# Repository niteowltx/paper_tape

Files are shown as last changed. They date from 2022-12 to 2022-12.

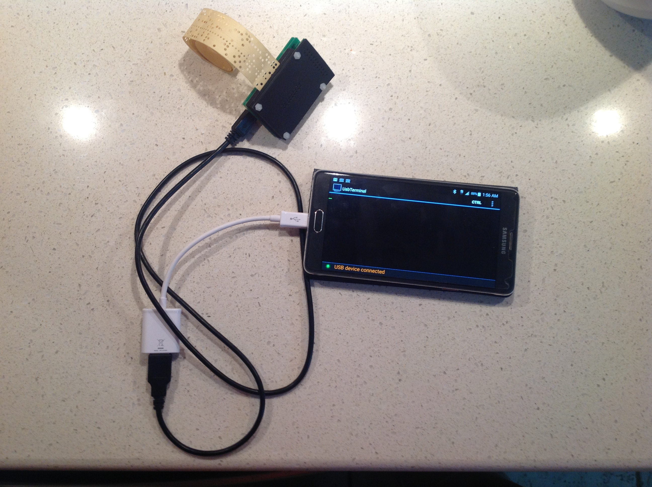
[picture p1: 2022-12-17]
paper_tape.jpg

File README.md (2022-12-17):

A Paper Tape Reader for ancient ASR33 class paper tapes.

	Paper is 1" wide with 9 holes on 0.1" centers.  Rows are also 0.1" apart.
	Data holes are 0.072" diameter, sprocket hole is 0.046" diameter
	Sprocket is small so it works as a strobe for the data

	Paper Tape layout:
		D0 D1 D2 St D3 D4 D5 D6 D7

Hardware:
	3D printed paper tape guide (top and bottom)

	top board: IR LED array (OSRAM SFH-4949), pullup resistor network (2K ohms)

	bottom board: Photo diode array (OSRAM BPX89), pulldown resistor network (1K ohms)

	process board: Adafruit Metro Mini, USB power and serial in/out

	Top and Bottom boards are identical, just flipped and populated differently.  Top
		board (IR LED) only connects +5 and Gnd.

	Signal cleanup between the Photodiode array and the Arduino are not necessary
		since the ATmega328 has Schmitt triggers built in.

	Photodiode Array to Arduino wiring:

		D0 -> PB0 -> Digital Pin 8
		D1 -> PB1 -> Digital Pin 9
		D2 -> PB2 -> Digital Pin 10
		D3 -> PB3 -> Digital Pin 11
		D4 -> PB4 -> Digital Pin 12
		D5 -> PD5 -> Digital Pin 5
		D6 -> PD6 -> Digital Pin 6
		D7 -> PD7 -> Digital Pin 7
		St -> PD2 -> Digital Pin 2 (INT0)

		To read all 8 bits in 2 reads from I/O Ports:
			byte = (PINB & 0x1F) | (PIND & 0xE0);

Software:
	Strobe generates interrupt on Arduino which reads byte and puts it in a FIFO.
		FIFO is 1000 bytes deep to allow for irregularites in serial output and
		the speed at which the loop() function is called.

	Main loop pulls bytes from FIFO and sends them via USB serial to host.

	Bytes are printed in HEX and a 2-character ASCII representaion of the lower 7-bits

	Serial output is set to 115200 which is fast enough for 96 ft/sec when the raw bytes
		from the tape are just sent over the serial port.  Printing bytes with a little formatting
		in HEX and printable ASCII reduces this to 16 ft/sec.

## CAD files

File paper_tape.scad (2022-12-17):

$fn					= 32;
//
// Paper Tape Reader
//
//	Paper guide and holder for IR LED & Photodiode arrays
//
// all dimensions in mm
//

// Paper tape dimensions (EIA Std RS-227 / RS-244)
perf_pitch		= 2.540;				// distance between punches on paper (horizontal and vertical)
perf_count		= 9;					// perforations per row
paper_width		= (perf_count+1)*perf_pitch; // (1 inch)
perf_small_r		= (1.1684/2);		// feed hole radius (0.046 inch diameter)
perf_large_r		= (1.8288/2);		// data hole radius (0.072 inch diameter)
paper_thick		= 0.10;				// paper thickness
strip_len	= 29;							// sample paper strip length, in frames

// Sensor dimensions
sensor_width		= perf_pitch+1;		// slightly wider than perf_pitch to accomodate sensor leads
sensor_height	= 3.632;				// height of ir led and photodiode arrays

// Paper tape guide
plate_w			= 38.1;			// 1.5 in
plate_h			= 53.34;			// 2.1 in
guide_offset		= sensor_height/3;	// raise top and lower bottom paper guide slot by this much

// PCB parameters
pcb_w				= plate_w;						// 1.5 in
pcb_h				= plate_h + (perf_pitch*4);	// 2.5 in
pcb_thick			= 1.5;

// Mounting screw hole diameter and radius
mhole_d			= 3;					// M3 nylon screws and nuts
mhole_r			= mhole_d/2;

module paper(n)
{
	color("Green")
	for(i=[0:n-1])
	translate([0,perf_pitch*i,0])
	difference(){
		cube([paper_width,perf_pitch,paper_thick]);
		for(p=[1:perf_count]){
			if(p==4)
				translate([(perf_pitch)*p,perf_pitch/2,0])
					cylinder(r=perf_small_r,h=paper_thick*3,center=true);
			else
				translate([(perf_pitch)*p,perf_pitch/2,0])
					cylinder(r=perf_large_r,h=paper_thick*3,center=true);
		}
	}
}

module mounting_holes(thick)
{
		translate([ plate_w/2-mhole_d, plate_h/2-mhole_d,0])cylinder(r=mhole_r,h=thick*2,center=true);
		translate([-plate_w/2+mhole_d, plate_h/2-mhole_d,0])cylinder(r=mhole_r,h=thick*2,center=true);
		translate([ plate_w/2-mhole_d,-plate_h/2+mhole_d,0])cylinder(r=mhole_r,h=thick*2,center=true);
		translate([-plate_w/2+mhole_d,-plate_h/2+mhole_d,0])cylinder(r=mhole_r,h=thick*2,center=true);
}

module bracket(thick)
{
	difference() { 
		cube(size=[plate_w,plate_h,thick],center=true);		// base
		mounting_holes(thick);

	}
}

module sensor_slot()
{
	cube(size=[sensor_width,perf_pitch*perf_count,sensor_height+20],center=true);	// sensor slot
}

module paper_guide_bottom()
{
	color("SteelBlue")
	difference() {
		rotate(180,[0,1,0])bracket(sensor_height+guide_offset);
		sensor_slot();
		translate([0,0,sensor_height-guide_offset])cube(size=[plate_h+1,paper_width,sensor_height],center=true);	// paper guide
	}
}

module paper_guide_top()
{
	color("LightSteelBlue")
	difference() {
		union() {
			bracket(sensor_height-guide_offset);
			translate([0,0,-guide_offset])cube(size=[plate_w,paper_width,sensor_height],center=true); // paper guide
		}
		sensor_slot();
	}
}

module holes(n)
{
	for(i=[0:n-1])
	translate([0,perf_pitch*i,0])
		cylinder(r=perf_pitch/4,h=5,center=true);
	

}

module resistor_pack()
{
	rotate(90,[0,0,1])
	translate([plate_h/2+perf_pitch,(-perf_pitch*10)/2,0])
	holes(10);
}

module connector()
{
	rotate(90,[0,0,1])
	translate([plate_h/2+(perf_pitch*2),(-perf_pitch*10)/2,0])
	holes(11);
}

module sensor_board()
{
	color("Yellow")
	difference() {
		translate([0,perf_pitch*2,0])cube(size=[pcb_w,pcb_h,pcb_thick],center=true);	// circuit board
		translate([perf_pitch/2,(-perf_pitch*8)/2,0])holes(9);	// sensor holes
		translate([-perf_pitch/2,(-perf_pitch*8)/2,0])holes(9);	// sensor holes
		mounting_holes(2);		// mounting holes
		resistor_pack();
		connector();
	}
}

module dip(pins,spacing)
{
	translate([-spacing/2,0,0])holes(pins);
	translate([spacing/2,0,0])holes(pins);
}

module main_board()
{
	color("Orange")
	difference() {
		translate([0,perf_pitch*2,0])cube(size=[pcb_w,pcb_h,pcb_thick],center=true);	// circuit board
		mounting_holes(2);		// mounting holes
		connector();
		translate([0,-perf_pitch*7,0])dip(14,perf_pitch*6);	// Adafruit Metro Mini
	}
}

module assembly()
{
	translate([0,0,0])paper_guide_bottom();
	translate([0,0,sensor_height*2])paper_guide_top();
	translate([0,0,-sensor_height*1])sensor_board();	// bottom board: photodiodes
	rotate(180,[0,1,0])translate([0,0,-sensor_height*2.5])sensor_board();	// top board: IR led's
	translate([0,0,-sensor_height*2])main_board();		// main board: arduino
	rotate(90,[0,0,-1])translate([-paper_width/2,-(perf_pitch*strip_len/2),1])paper(strip_len);
}

module all()
{
	assembly();
}

module pieces()
{
	rotate(180,[0,1,0])translate([plate_w*.66,0,0])paper_guide_top();
	translate([plate_w*.66,0,0])paper_guide_bottom();
	translate([plate_w*0.66,pcb_h,0])sensor_board();
	translate([-plate_w*0.66,pcb_h,0])sensor_board();
	translate([plate_w*2,0,0])main_board();
}

all();
//pieces();

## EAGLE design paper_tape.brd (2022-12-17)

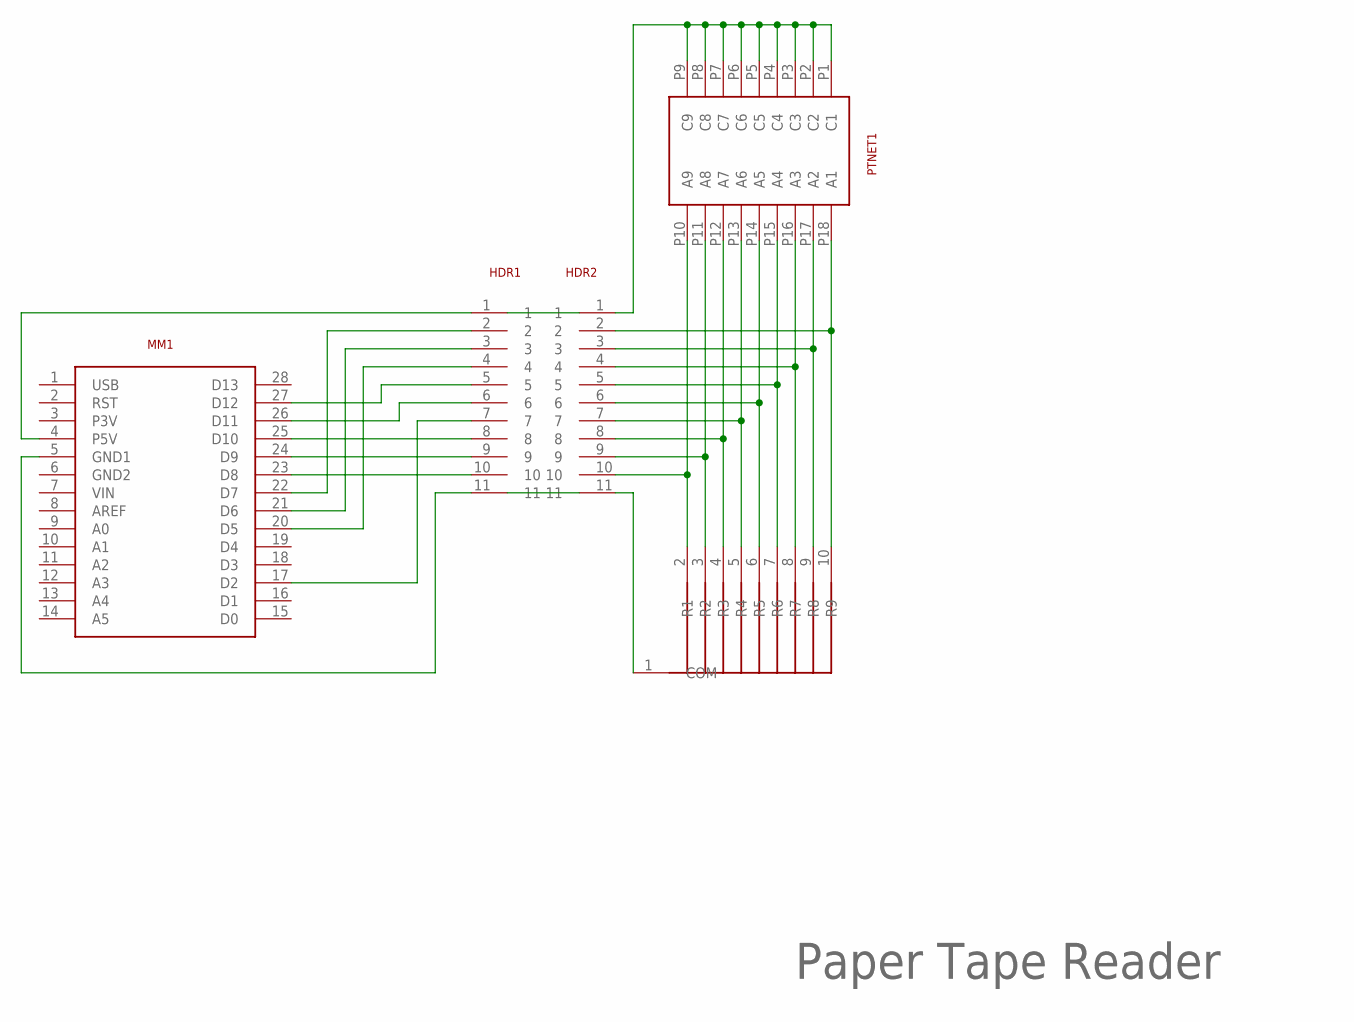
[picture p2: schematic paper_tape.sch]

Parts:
HDR1, HDR2: HEADER; SIP11
MM1: METRO_MINI; DIP28
PTNET1: PBX89; DIP18N
RN1: 1k; SIP10

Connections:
GND: HDR1.11, HDR2.11, MM1.5 (GND1), RN1.1 (COM)
unnamed: HDR1.7, MM1.17 (D2)
unnamed: HDR1.6, MM1.26 (D11)
unnamed: HDR1.5, MM1.27 (D12)
unnamed: HDR1.4, MM1.20 (D5)
unnamed: HDR1.3, MM1.21 (D6)
unnamed: HDR1.2, MM1.22 (D7)
unnamed: HDR1.1, MM1.4 (P5V)
unnamed: HDR1.8, MM1.25 (D10)
unnamed: HDR1.9, MM1.24 (D9)
unnamed: HDR1.10, MM1.23 (D8)
P5V: HDR2.1, PTNET1.P1 (C1), PTNET1.P2 (C2), PTNET1.P3 (C3), PTNET1.P4 (C4), PTNET1.P5 (C5), PTNET1.P6 (C6), PTNET1.P7 (C7), PTNET1.P8 (C8), PTNET1.P9 (C9)
PT_D0: HDR2.10, PTNET1.P10 (A9), RN1.2 (R1)
PT_D1: HDR2.9, PTNET1.P11 (A8), RN1.3 (R2)
PT_D2: HDR2.8, PTNET1.P12 (A7), RN1.4 (R3)
PT_D3: HDR2.6, PTNET1.P14 (A5), RN1.6 (R5)
PT_D4: HDR2.5, PTNET1.P15 (A4), RN1.7 (R6)
PT_D5: HDR2.4, PTNET1.P16 (A3), RN1.8 (R7)
PT_D6: HDR2.3, PTNET1.P17 (A2), RN1.9 (R8)
PT_D7: HDR2.2, PTNET1.P18 (A1), RN1.10 (R9)
PT_STROBE: HDR2.7, PTNET1.P13 (A6), RN1.5 (R4)

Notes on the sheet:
Paper Tape Reader

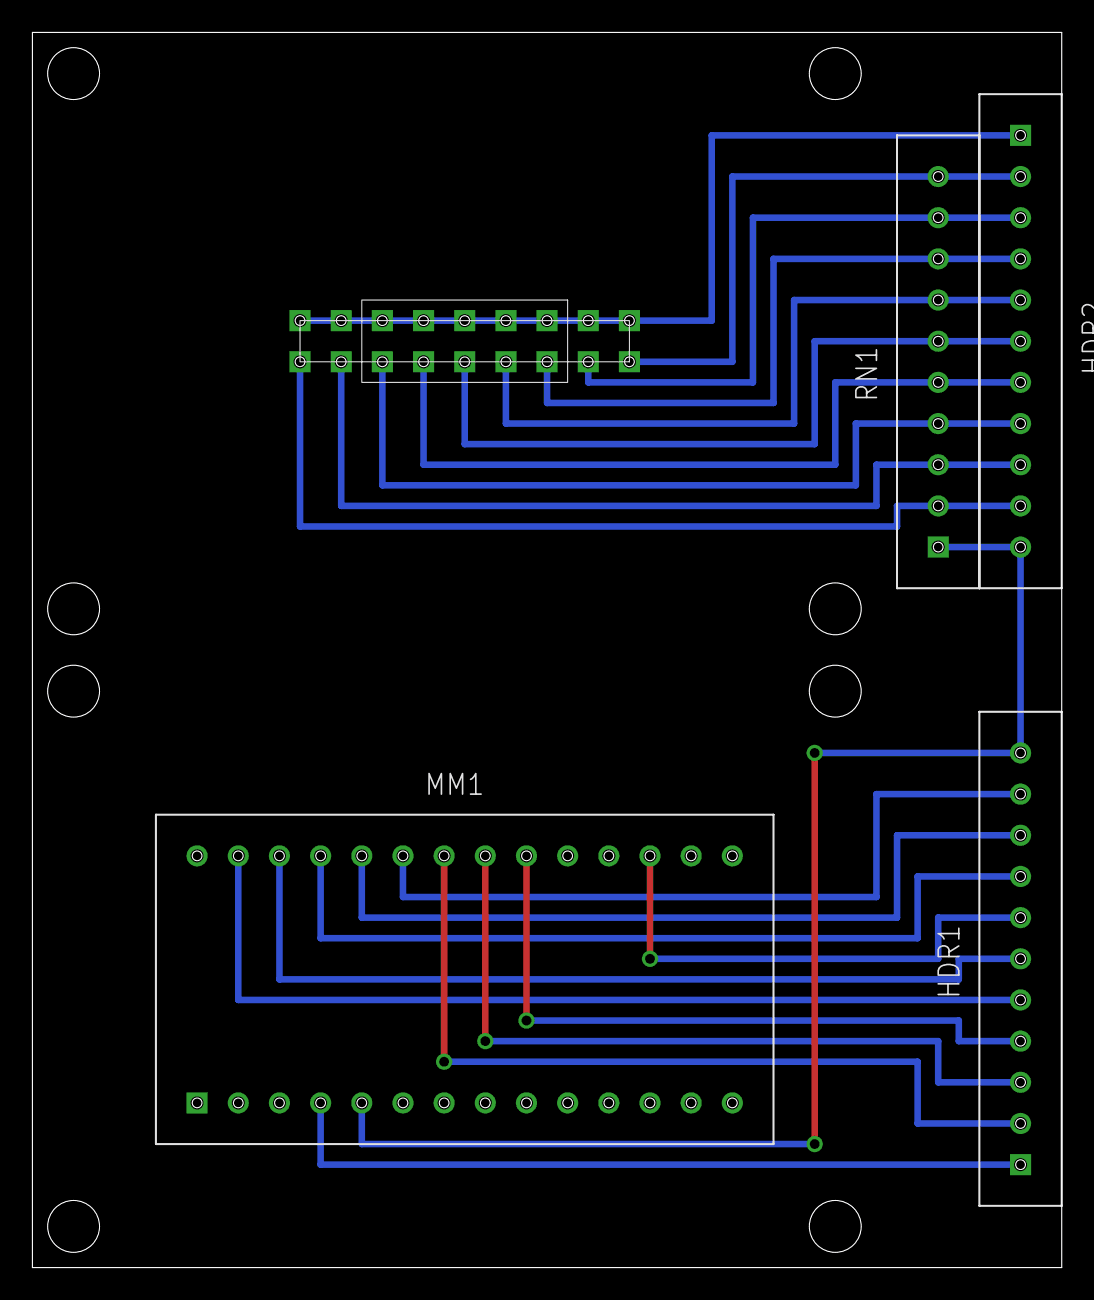
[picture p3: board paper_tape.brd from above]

Board: 2 copper layers, 63.5 x 76.2 mm, 5 parts (0 on the bottom side), 21 nets.

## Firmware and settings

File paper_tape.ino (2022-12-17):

//
// Paper Tape Reader
//
// Read data from ancient paper tapes.  Tape is 1" wide with 8 data
// holes and 1 sprocket hole which is used to strobe the data since it
// is slightly smaller than the data holes.
//
// There are 9 inputs from the photodiode array: D0-D7 and Strobe
// The tape layout is:  D0 D1 D2 Strobe D3 D4 D5 D6 D7
//
// The rising strobe pin is attaced to an interrupt handler which
// picks up the current byte and puts it in a FIFO.  The main
// processing loop simply waits for characters to arrive in the FIFO
// and sends them out the serial port.
//
// Normally pins are read via digitalRead() but to do it faster
// we read the ports directly.  There is no single port with all 8
// pins available, so we use PINB and PIND which can be combined
// to make the whole 8-bit value.
//
//  There are only 5 electronic components:
//	Arduino Metro Mini (Adafruit)
//	IR Led Array (OSRAM SFH-4949)
//	Photodiode Array (OSRAM BPX-89)
//	Led pullup array (2K, 10-pin SIP)
//	Diode pulldown array (1K, 10-pin SIP)
//
//  Similar designs use Schmitt trigger buffers (74HC14 or similar) to
//  clean up the input signal, but the Arduino (ATmeta328) already has
//  Schmitt triggers built-in so these are unnecessary.
//

int Strobe = 2;  // PD2, INT0
int D0 = 8;      // PB0
int D1 = 9;      // PB1
int D2 = 10;     // PB2
int D3 = 11;     // PB3
int D4 = 12;     // PB4
int D5 = 5;      // PD5
int D6 = 6;      // PD6
int D7 = 7;      // PD7
int Mpin = 3;    // Select output mode: 1=ASCII or 0=HEX+ASCII
int Error = LED_BUILTIN;  // Red LED

int Mode = 0; // selected output mode

// Current data byte
static inline unsigned char pt_byte() { return (PINB & 0x1F) | (PIND & 0xE0); }

// 2-byte printable version of ASCII character table
const char *Ascii[] = {
	"\\0", "^A", "^B", "^C", "^D", "^E", "^F", "^G",
	"^H", "^I", "LF", "^K", "^L", "CR", "^N", "^O",
	"^P", "^Q", "^R", "^S", "^T", "^U", "^V", "^W",
	"^X", "^Y", "^Z", "^[", "^\\", "^]", "^^", "^_",
	"SP", "! ", "\" ", "# ", "$ ", "% ", "& ", "' ",
	"( ", ") ", "* ", "+ ", ", ", "- ", ". ", "/ ",
	"0 ", "1 ", "2 ", "3 ", "4 ", "5 ", "6 ", "7 ",
	"8 ", "9 ", ": ", "; ", "< ", "= ", "> ", "? ",
	"@ ", "A ", "B ", "C ", "D ", "E ", "F ", "G ",
	"H ", "I ", "J ", "K ", "L ", "M ", "N ", "O ",
	"P ", "Q ", "R ", "S ", "T ", "U ", "V ", "W ",
	"X ", "Y ", "Z ", "[ ", "\\ ", "] ", "^ ", "_ ",
	"` ", "a ", "b ", "c ", "d ", "e ", "f ", "g ",
	"h ", "i ", "j ", "k ", "l ", "m ", "n ", "o ",
	"p ", "q ", "r ", "s ", "t ", "u ", "v ", "w ",
	"x ", "y ", "z ", "{ ", "| ", "} ", "~ ", "DL"
};

char Hexstr[] = "0123456789ABCDEF";

// FIFO
volatile int	In = 0;
volatile int	Out = 0;
#define FIFO_SIZE	512
volatile unsigned char Fifo[FIFO_SIZE];


// put one byte into fifo, discard if full
static inline void
fifo_put(unsigned char c)
{
	int next_in = In+1;

	if( next_in >= FIFO_SIZE )
		next_in = 0;
	if( next_in != Out ) {	// if not full, add it
		Fifo[In] = c;
		In = next_in;
		}
	else {
		digitalWrite(Error,HIGH); // indicate some bytes were dropped
	}
}

// get one byte from fifo, return 0 if empty
static inline unsigned char
fifo_get()
{
	unsigned char c;
	int next_out = Out+1;

	if(next_out >= FIFO_SIZE )
		next_out = 0;
	if( In != Out ){
		c = Fifo[Out];
		Out = next_out;
		}
	else
		c = 0;

	return c;
}

// test fifo empty
static inline int
fifo_empty()
{
	return In == Out;
}

// get 8 bits from the combined ports B and D, put byte in fifo
void
capture()
{
	fifo_put( pt_byte() );
}

// Print a byte on the serial output.  Show in HEX and ASCII
static inline void
display_hex_ascii(unsigned char b)
{
	static char outstr[6] = "xx aa";
	const char *a = Ascii[b&0x7F];

	outstr[0] = Hexstr[b>>4];
	outstr[1] = Hexstr[b&0xF];
	outstr[3] = a[0];
	outstr[4] = a[1];
	Serial.println(outstr);
}

// Print byte as ASCII.  Strip parity, discard NULL or DEL
// Show non-printable characters in hex as: {XX} 
static inline void
display_ascii(unsigned char b)
{
	static char outstr[5] = "{XX}";

	b &= 0x7F;
	if( b==0x00 || b==0x7F )
		return;
	if( isPrintable(b) || isSpace(b) )
		Serial.write(b);
	else{
		outstr[1] = Hexstr[b>>4];
		outstr[2] = Hexstr[b&0xF];
		Serial.print(outstr);
	}
}

static inline void
display(unsigned char b)
{
	if(Mode)
		display_ascii(b);
	else
		display_hex_ascii(b);
}

void
setup()
{
	pinMode(Strobe, INPUT);
	pinMode(D0,     INPUT);
	pinMode(D1,     INPUT);
	pinMode(D2,     INPUT);
	pinMode(D3,     INPUT);
	pinMode(D4,     INPUT);
	pinMode(D5,     INPUT);
	pinMode(D6,     INPUT);
	pinMode(D7,     INPUT);
	pinMode(Mpin,   INPUT_PULLUP);
	pinMode(Error,  OUTPUT);

	digitalWrite(Error, LOW);
	Mode = digitalRead(Mpin);

	Serial.begin(115200);	// fast enough to keep up at 96 ft/sec RAW, 16 ft/sec hex+ascii

	// capture bytes on RISING edge.  This gives the data holes maximum time
	// to stabilize before sampling them.
	attachInterrupt(digitalPinToInterrupt(Strobe), capture, FALLING);
}

void
loop()
{
	while( !fifo_empty() )
		display(fifo_get());
}
